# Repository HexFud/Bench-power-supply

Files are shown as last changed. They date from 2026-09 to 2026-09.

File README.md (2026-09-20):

# Bench-power-supply

I designed a simple and cost effective bench power supply for everyone.
To simplify the assmebly process i designed in kicad a small pcb where you connect external components

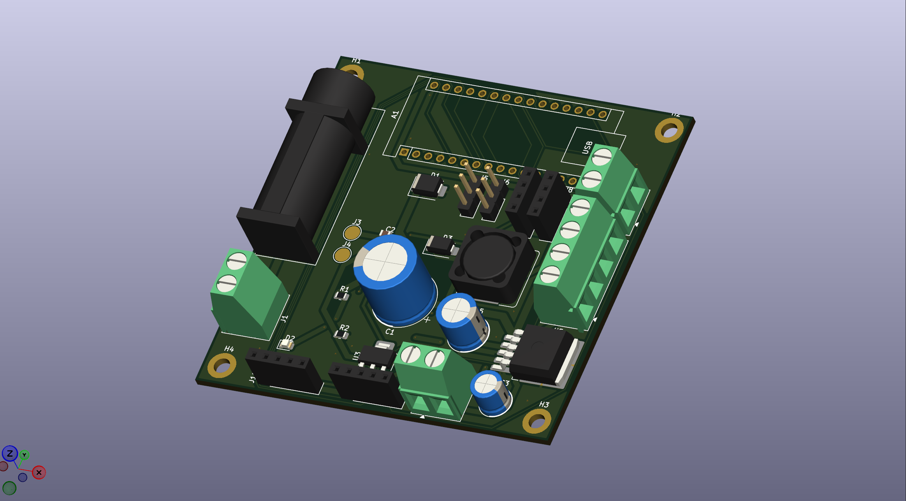
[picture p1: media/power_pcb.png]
PCB 3D model
 

## Specifications
* IN Voltage: 24V DC
* Power Module: compatible with buck modules CC/CV based on XL4015 (5A) or XL4016 (8A)

## Included Protections
* 6.3A fusible
* schottky diode to protect against invers polarity
* filtering capacitor

## First power-up

1. Do not plug the Nano, the DPS and the displays yet.
2. Power the PCB with 24V and check the 12V rail after the LM2596 and the 3V3 rail.
3. Power off, plug everything in, and power on again with no load on the output.
4. The output stays OFF at boot; enable it with a long press on the voltage encoder.

## Firmware

* Arduino IDE, board "Arduino Nano ESP32"
* Libraries: Adafruit SSD1306, Adafruit GFX Library
* Firmware: `Firmware/bench_psu.ino`
* Register addresses and scales are constants at the top of the sketch: check them against
  the protocol document of your DPS module.

## ⚠️ Crucial Assembly Notes

1. **Modifying the Buck Converter:** 
   To mount the voltage and current controls on the front panel, you must physically desolder the original tiny blue trimmers from the purchased Buck module. Solder wires into those remaining through-holes and route them to your front-panel potentiometers.
2. **Display Wiring (CRITICAL - DO NOT BURN YOUR DISPLAY):** 
   When using the standard 5-wire Chinese dual meters (3 thin wires, 2 thick wires), **THE THIN BLACK WIRE MUST BE LEFT UNCONNECTED**. The meter derives its ground reference entirely through the thick black wire. Connecting both black wires creates a ground loop that will melt the thin wire instantly under load. (Connector `J8` on this PCB is purposely designed with only 3 pins for the thin wires).
3. **High-Current Traces:** 
   The PCB tracks handling the 24V input, the Buck module, and the outputs carry up to 5–8A. When routing the PCB, ensure power traces are made very wide (min. 2mm–3mm) or left exposed so you can reinforce them with solder.

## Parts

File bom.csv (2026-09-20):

Ref | Qty | Component | Value / Notes | KiCad Footprint | Supplier | LCSC Search Link | Est. Price USD (line total)
A1 | 1 | Arduino Nano ESP32 |  | Module:Arduino_Nano | Arduino Store / Mouser | https://it.aliexpress.com/item/1005009296627043.html | 5
C1 | 1 | Electrolytic capacitor | 1000uF 50V, radial 12.5 mm | Capacitor_THT:CP_Radial_D12.5mm_P5.00mm | LCSC | https://www.lcsc.com/search?q=1000uF+50V+radial | 0,82
C2 | 1 | Ceramic capacitor | 100nF 50V X7R, 0805 | Capacitor_SMD:C_0805_2012Metric | LCSC | https://www.lcsc.com/search?q=100nF+50V+0805 | 0,94
C3 | 1 | Electrolytic capacitor | 100uF 25V, radial 6.3 mm (change symbol to C_Polarized) | Capacitor_THT:CP_Radial_D6.3mm_P2.50mm | LCSC | https://www.lcsc.com/search?q=100uF+25V+radial | 0.1
C4 | 1 | Tantalum capacitor | 22uF 16V, case B (AMS1117 stability) | Capacitor_Tantalum_SMD:CP_EIA-3528-21_Kemet-B | LCSC | https://www.lcsc.com/search?q=22uF+16V+tantalum | 0.2
C5 | 1 | Low-ESR electrolytic capacitor | 220uF 25V or higher, radial 8 mm (change symbol to C_Polarized) | Capacitor_THT:CP_Radial_D8.0mm_P3.50mm | LCSC | https://www.lcsc.com/search?q=220uF+25V+low+ESR | 0.3
D1 | 1 | SMBJ36A unidirectional TVS | Not the CA version (bidirectional) | Diode_SMD:D_SMB | LCSC | https://www.lcsc.com/search?q=SMBJ36A | 0.50
D2 | 1 | LED 0805 | Power indicator | LED_SMD:LED_0805_2012Metric | LCSC | https://www.lcsc.com/search?q=LED+0805 | 0.03
D3 | 1 | SS36 Schottky diode | 3A 60V, SMA | Diode_SMD:D_SMA | LCSC | https://www.lcsc.com/search?q=SS36 | 0.15
F1 | 1 | 6.3A 5x20 fuse + fuse holder | Pick the holder first, then adapt the footprint | Fuse:Fuseholder_Cylinder-5x20mm_Bulgin_FX0457_Horizontal_Closed | LCSC | https://www.lcsc.com/search?q=5x20+fuse+holder+PCB | 1.0
J1 | 1 | 2-pin screw terminal | 5.08 mm, 24V input | TerminalBlock_Phoenix:TerminalBlock_Phoenix_MKDS-1,5-2-5.08_1x02_P5.08mm_Horizontal | LCSC | https://www.lcsc.com/search?q=5.08mm+screw+terminal+2P | 0.5
J7 | 1 | 4-pin screw terminal | 5.08 mm, to the DPS module | TerminalBlock_Phoenix:TerminalBlock_Phoenix_MKDS-1,5-4-5.08_1x04_P5.08mm_Horizontal | LCSC | https://www.lcsc.com/search?q=5.08mm+screw+terminal+4P | 0.8
J2, J8 | 2 | 1x4 female header | I2C displays (GND, 3V3, SDA, SCL): check the pin order of your modules | Connector_PinSocket_2.54mm:PinSocket_1x04_P2.54mm_Vertical | LCSC | https://www.lcsc.com/search?q=female+header+1x4+2.54 | 0.3
J9, J10 | 2 | 1x5 female header | Encoders (GND, 3V3, SW, DT, CLK) | Connector_PinSocket_2.54mm:PinSocket_1x05_P2.54mm_Vertical | LCSC | https://www.lcsc.com/search?q=female+header+1x5+2.54 | 0.3
J5 | 1 | 1x3 female header | Serial to DPS (TX, RX, GND); delete J6 | Connector_PinSocket_2.54mm:PinSocket_1x03_P2.54mm_Vertical | LCSC | https://www.lcsc.com/search?q=female+header+1x3+2.54 | 0.2
L1 | 1 | Power inductor | 47uH, at least 3.5A (e.g. SRR1260 series); check the LM2596 datasheet nomograph | Inductor_SMD:L_Bourns_SRR1260 | LCSC | https://www.lcsc.com/search?q=SRR1260-470M | 1.50
R1, R2 | 2 | 10k resistor | 0805 | Resistor_SMD:R_0805_2012Metric | LCSC | https://www.lcsc.com/search?q=10k+0805 | 0.04
U3 | 1 | AMS1117-3.3 regulator | SOT-223 (fed from the 12V rail) | Package_TO_SOT_SMD:SOT-223-3_TabPin2 | LCSC | https://www.lcsc.com/search?q=AMS1117-3.3 | 0.2
U5 | 1 | LM2596S-12 regulator | TO-263-5 | Package_TO_SOT_SMD:TO-263-5_TabPin3 | LCSC | https://www.lcsc.com/search?q=LM2596S-12 | 1.5
- | 1 | Riden DPS5005 communication version | Programmable buck 0-50V 5A, 6-55V input, Modbus serial. With a 24V input the output tops out around 23V | - | AliExpress / Amazon / Riden resellers | https://it.aliexpress.com/item/1005003611553445.html | 30
SW1, SW2 | 2 | SPST switch 10A DC | Rated for DC current | (external, on terminals) | Amazon / AliExpress | https://it.aliexpress.com/item/1005005261096988.html | 4.0
- | 2 | 0.96 inch I2C OLED display | Check pin order (GND, VCC, SCL, SDA) | (external) | Amazon / AliExpress | https://it.aliexpress.com/item/1005006141235306.html | 6.0
- | 2 | KY-040 encoder module | Correct pin-to-pin cable to J9/J10 | (external) | Amazon / AliExpress | https://it.aliexpress.com/item/1005006060621481.html | 3.0
- | 2 | Encoder knob | May be included with encoder purchase | (external) | Amazon / AliExpress |  | 2.0
- | 1 | Banana binding post pair (red and black) | Rated for 5A | (external) | Amazon / AliExpress | https://it.aliexpress.com/item/1005005610222281.html | 4.0
- | 1 | 24V DC power supply | At least 5A | (external) | Amazon / AliExpress | https://www.amazon.it/Security-01-Alimentatore-spina-Plug-XH2400-1500WG/dp/B0CJFH8T6C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 | 13
- | 1 | Custom PCB (batch of 5-10) | Fabrication + shipping | (Gerber files) | JLCPCB or similar |  | 20
- | 1 | 2-channel oscilloscope | for ripple and noise analysis | (external) | Amazon / AliExpress | https://it.aliexpress.com/item/1005009751654965.html | 160.0
TOTAL |  |  |  |  |  |  | 254

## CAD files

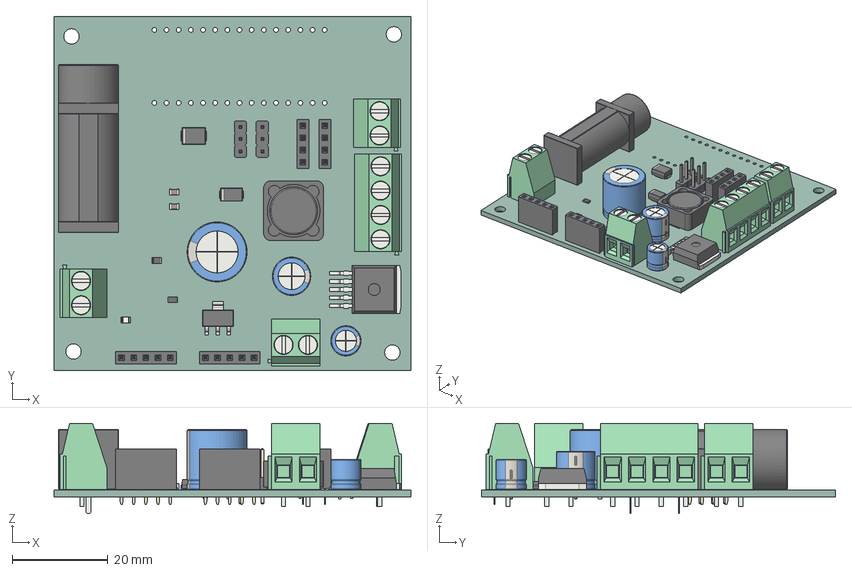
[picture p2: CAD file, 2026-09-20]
CAD/PCB_3DModel.step
74.4 x 73.9 x 18.8 mm
C_0805_2012Metric x 2
TerminalBlock_Phoenix_MKDS-1,5-2-5.08_1x02_P5.08mm_Horizontal x 3
PinSocket_1x05_P2.54mm_Vertical x 2
R_0805_2012Metric x 2
PinHeader_1x03_P254mm_Vertical x 2
SRR1260
a648ce37-9c39-11ed-93f0-dde97e994e83_part
a648ce38-9c39-11ed-93f0-dde97e994e83_part
a648ce39-9c39-11ed-93f0-dde97e994e83_part
D_SMB
CP_Radial_D63mm_P250mm
CP_Radial_D80mm_P350mm
SOT-223
PinSocket_1x04_P2.54mm_Vertical x 2
LED_0805_2012Metric
CP_Radial_D125mm_P500mm
D_SMA
TerminalBlock_Phoenix_MKDS-1,5-4-5.08_1x04_P5.08mm_Horizontal
A_Bulgin_FX0457
Bench_Power_supply_PCB

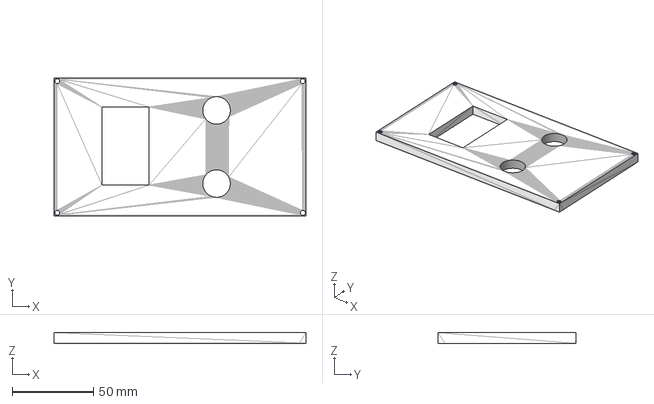
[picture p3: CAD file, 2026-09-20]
Production/PSU_CASE_FRONT.step
155.0 x 85.0 x 6.54 mm

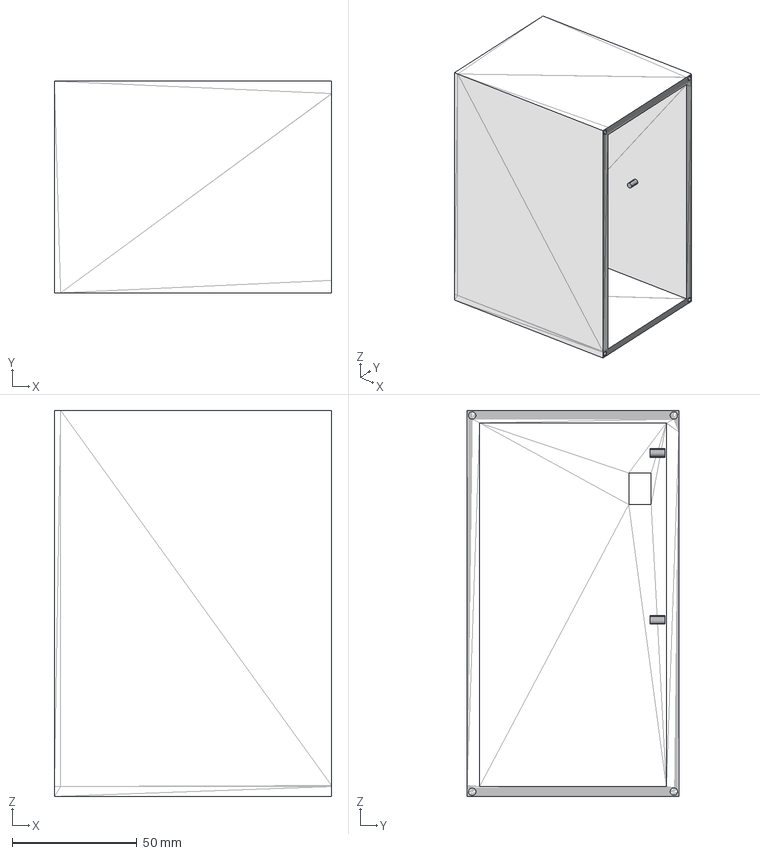
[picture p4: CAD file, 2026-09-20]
Production/PSU_CASE_BACK.step
111.3 x 85.0 x 155.0 mm

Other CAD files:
CAD/Power Supply.f3z

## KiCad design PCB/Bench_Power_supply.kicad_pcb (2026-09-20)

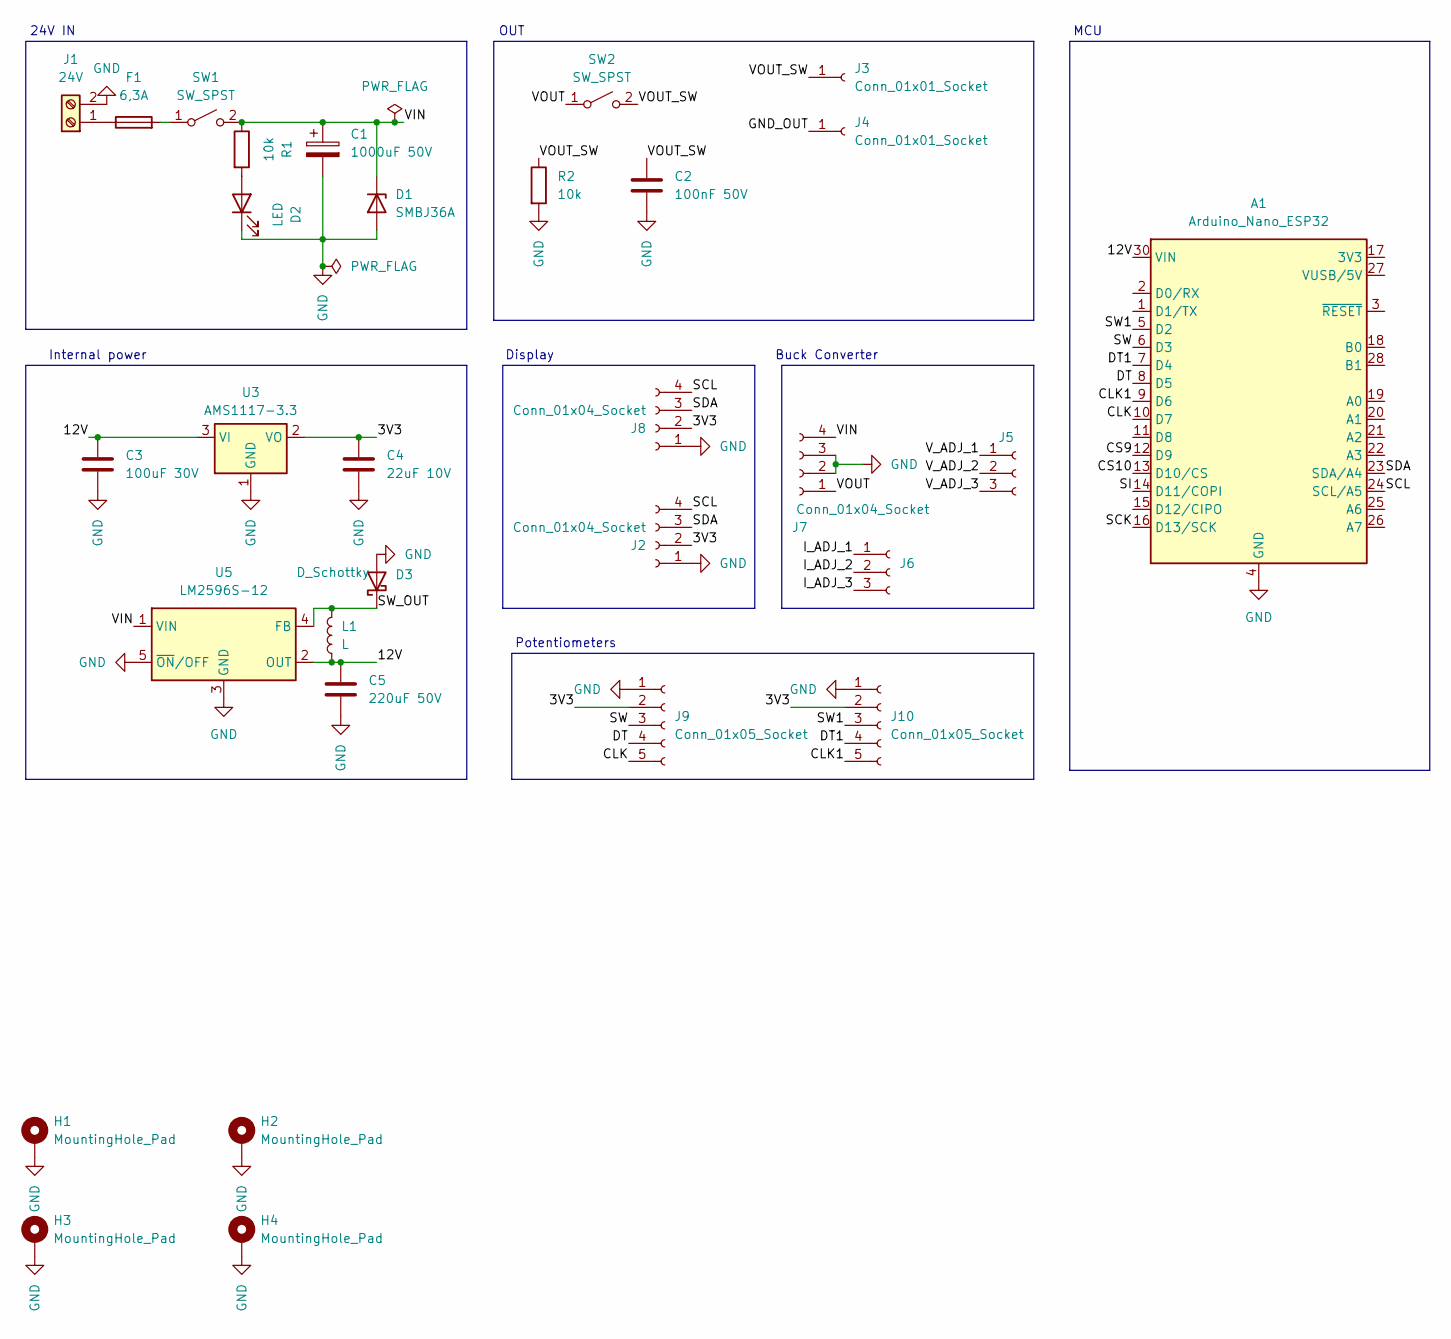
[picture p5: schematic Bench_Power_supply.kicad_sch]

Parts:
A1: Arduino_Nano_ESP32; Arduino_Nano
C1: 1000uF 50V; CP_Radial_D12.5mm_P5.00mm
C2: 100nF 50V; C_0805_2012Metric
C3: 100uF 30V; CP_Radial_D6.3mm_P2.50mm
C4: 22uF 10V; C_0805_2012Metric
C5: 220uF 50V; CP_Radial_D8.0mm_P3.50mm
D1: SMBJ36A; D_SMB
D2: LED; LED_0805_2012Metric
D3: D_Schottky; D_SMA
F1: 6,3A; Fuseholder_Cylinder-5x20mm_Bulgin_FX0457_Horizontal_Closed
H1, H2, H3, H4: MountingHole_Pad; MountingHole_3.2mm_M3_DIN965_Pad
J1: 24V; TerminalBlock_Phoenix_MKDS-1,5-2-5.08_1x02_P5.08mm_Horizont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
J2, J8: Conn_01x04_Socket; PinSocket_1x04_P2.54mm_Vertical
J3, J4: Conn_01x01_Socket; TestPoint_Pad_D3.0mm
J5, J6: Conn_01x03_Socket; PinHeader_1x03_P2.54mm_Vertical
J7: Conn_01x04_Socket; TerminalBlock_Phoenix_MKDS-1,5-4-5.08_1x04_P5.08mm_Horizont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
J9, J10: Conn_01x05_Socket; PinSocket_1x05_P2.54mm_Vertical
L1: L; L_Bourns_SRR1260
R1, R2: 10k; R_0805_2012Metric
SW1, SW2: SW_SPST; TerminalBlock_Phoenix_MKDS-1,5-2-5.08_1x02_P5.08mm_Horizont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
U3: AMS1117-3.3; SOT-223-3_TabPin2
U5: LM2596S-12; TO-263-5_TabPin3

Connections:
/3V3: C4.1, J2.2, J8.2, J9.2, J10.2, U3.2 (VO)
/12V: A1.30 (VIN), C3.1, C5.1, L1.1, U3.3 (VI), U5.2 (OUT)
/CLK: A1.10 (D7), J9.5
/CLK1: A1.9 (D6), J10.5
/CS9: A1.12 (D9)
/CS10: A1.13 (D10/CS)
/DT: A1.8 (D5), J9.4
/DT1: A1.7 (D4), J10.4
/GND_OUT: J4.1 (Pin_1_1)
/I_ADJ_1: J6.1
/I_ADJ_2: J6.2
/I_ADJ_3: J6.3
/SCK: A1.16 (D13/SCK)
/SCL: A1.24 (SCL/A5), J2.4, J8.4
/SDA: A1.23 (SDA/A4), J2.3, J8.3
/SI: A1.14 (D11/COPI)
/SW: A1.6 (D3), J9.3
/SW1: A1.5 (D2), J10.3
/SW_OUT: D3.1 (K), L1.2, U5.4 (FB)
/VIN: C1.1, D1.1 (K), J7.4, R1.1, SW1.2 (B), U5.1 (VIN)
/VOUT: J7.1, SW2.1 (A)
/VOUT_SW: C2.1, J3.1 (Pin_1_1), R2.1, SW2.2 (B)
/V_ADJ_1: J5.1
/V_ADJ_2: J5.2
/V_ADJ_3: J5.3
GND: A1.4 (GND), A1.29 (GND), C1.2, C2.2, C3.2, C4.2, C5.2, D1.2 (A), D2.1 (K), D3.2 (A), H1.1 (1_1), H2.1 (1_1), H3.1 (1_1), H4.1 (1_1), J1.2, J2.1, J7.2, J7.3, J8.1, J9.1, J10.1, R2.2, U3.1 (GND), U5.3 (GND), U5.5 (~ON/OFF)
unnamed: D2.2 (A), R1.2
unnamed: F1.1, J1.1
unnamed: F1.2, SW1.1 (A)

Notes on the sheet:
Internal power
Buck Converter
Display
Potentiometers
MCU
OUT
24V IN

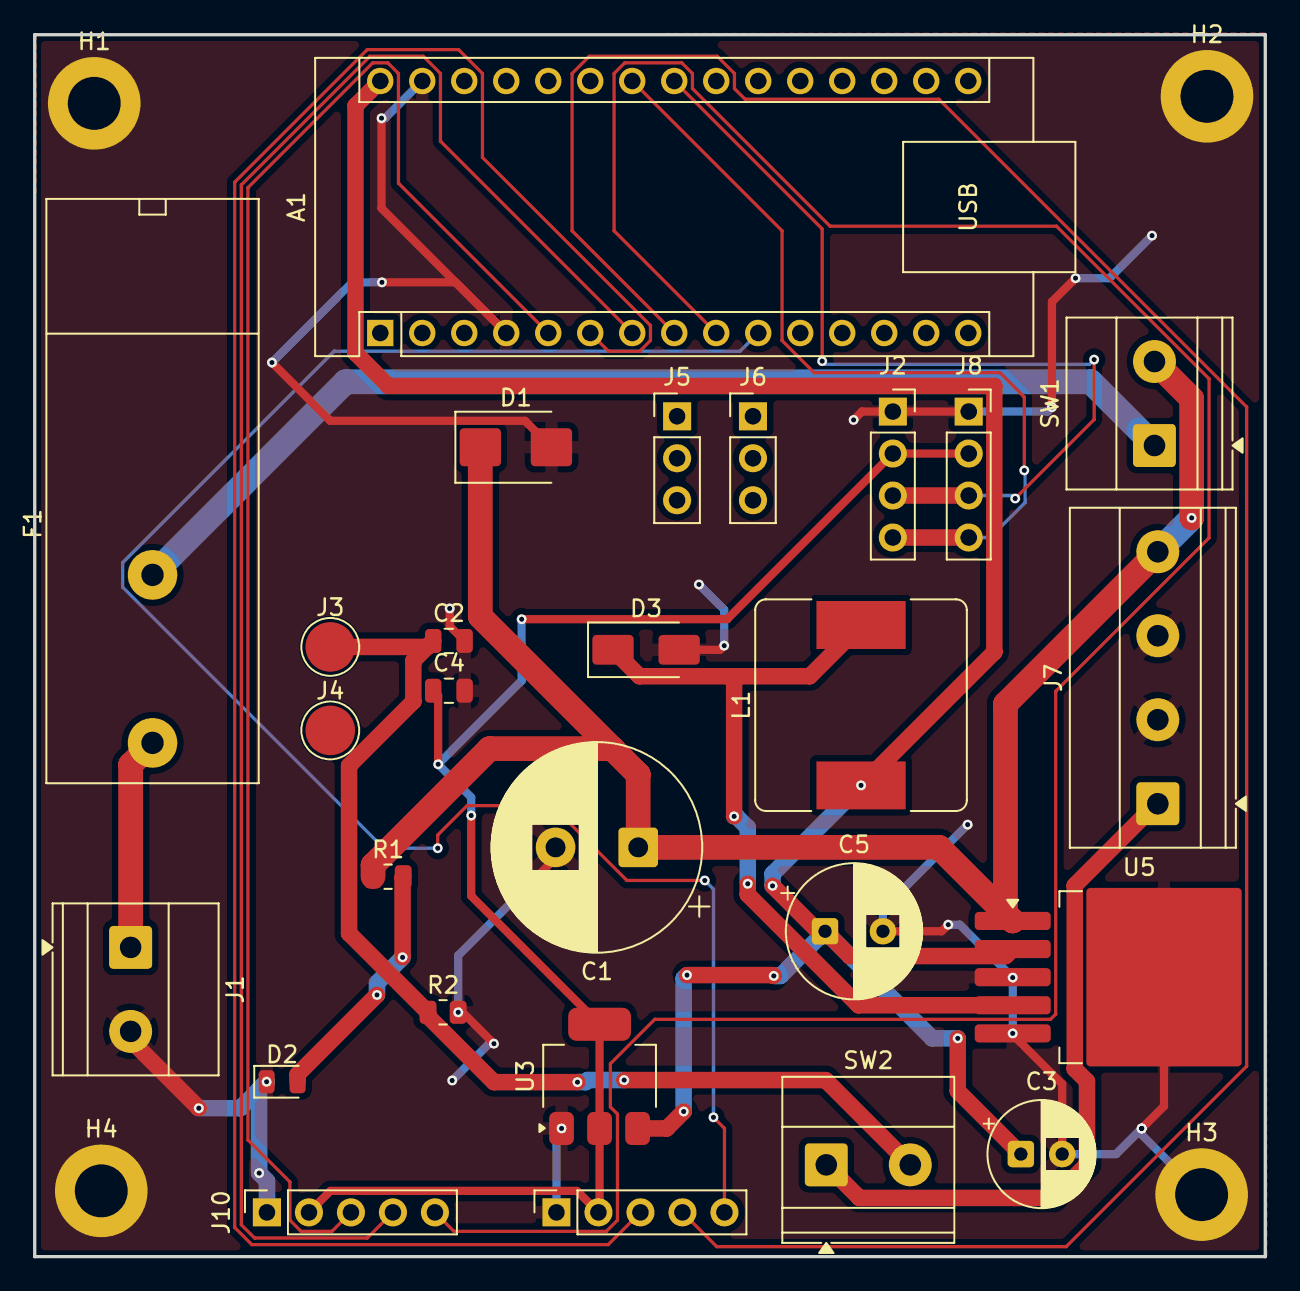
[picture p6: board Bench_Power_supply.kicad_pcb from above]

Board: 2 copper layers, 74.4 x 73.9 mm, 31 parts (0 on the bottom side), 18 nets.

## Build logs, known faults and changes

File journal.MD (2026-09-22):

## 19 September 1,14 Hours
This is the day 1 of building my own bench power supply. I started designing the schematic, and then routed the components on the PCB. Very easy job

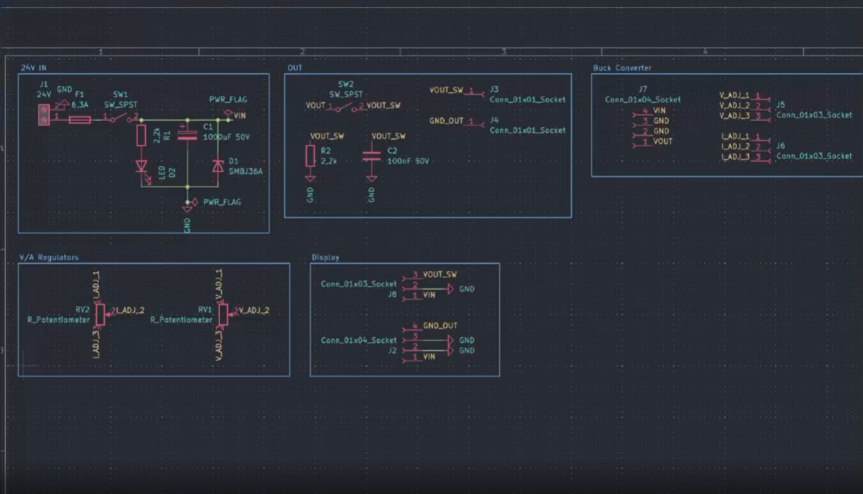
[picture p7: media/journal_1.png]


## 20 Septmeber 1,93 Hours
I have done a lot of progressed in only one day. I started the day by designing the case for the PCB 

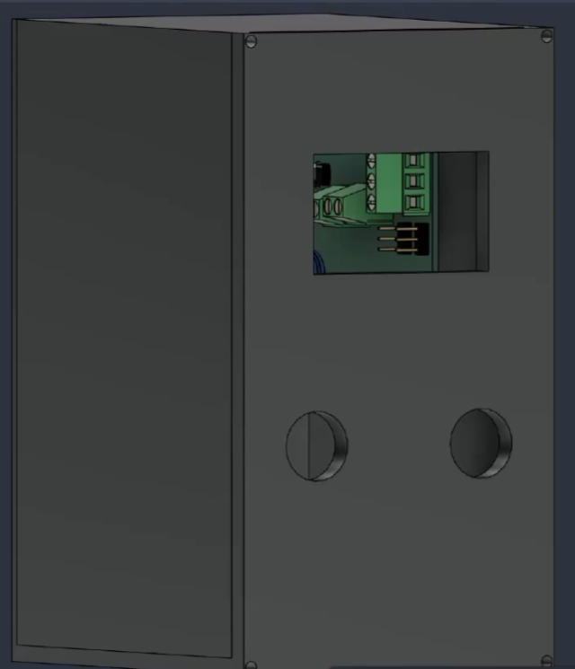
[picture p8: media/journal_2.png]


After procrastinating for a bit i thoutght about the PCB and i said to myself, this is to simple so I'm back editing the PCB! I added a lot of components to make the PSU "smart".

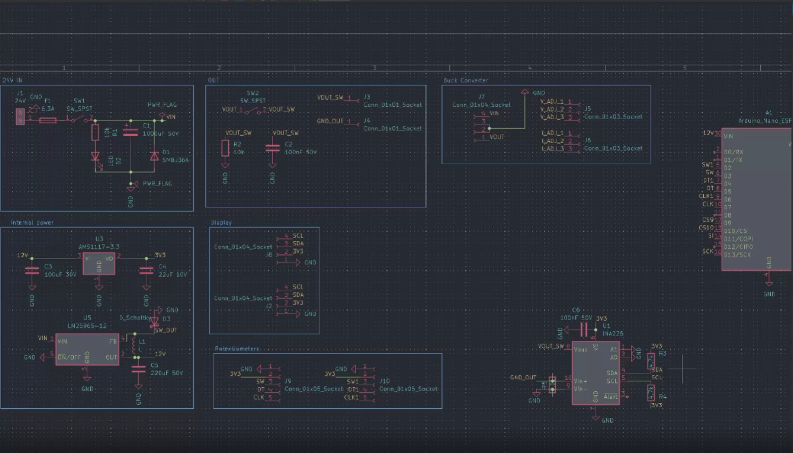
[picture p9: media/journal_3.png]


## 21 September 

I have polished the PCB and the 3D model a bit. I think this project is now complete but maybe i will update this again!

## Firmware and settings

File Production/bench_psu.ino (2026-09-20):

#include <Arduino.h>
#include <Wire.h>
#include <Adafruit_GFX.h>
#include <Adafruit_SSD1306.h>

static const uint8_t ENC_V_CLK = 10, ENC_V_DT = 8, ENC_V_SW = 6;
static const uint8_t ENC_I_CLK = 9, ENC_I_DT = 7, ENC_I_SW = 5;
static const uint8_t DPS_RX_PIN = 44;
static const uint8_t DPS_TX_PIN = 43;
static const uint8_t I2C_SDA_PIN = 11;
static const uint8_t I2C_SCL_PIN = 12;

static const bool ENC_V_INVERT = false;
static const bool ENC_I_INVERT = false;

static const uint8_t  DPS_ADDR = 1;
static const uint32_t DPS_BAUD = 9600;

static const uint16_t REG_USET   = 0x0000;
static const uint16_t REG_ISET   = 0x0001;
static const uint16_t REG_UOUT   = 0x0002;
static const uint16_t REG_IOUT   = 0x0003;
static const uint16_t REG_UIN    = 0x0005;
static const uint16_t REG_PROT   = 0x0007;
static const uint16_t REG_CVCC   = 0x0008;
static const uint16_t REG_ONOFF  = 0x0009;
static const uint16_t REG_COUNT  = 10;
static const float    V_SCALE = 100.0f;
static const float    I_SCALE = 1000.0f;

static const float V_MAX_CFG    = 23.0f;
static const float I_MAX_CFG    = 5.0f;
static const float VIN_HEADROOM = 1.5f;

static const float V_STEPS[] = {0.01f, 0.1f, 1.0f};
static const float I_STEPS[] = {0.001f, 0.01f, 0.1f};

#define USE_DISPLAY2 1
static const uint8_t OLED1_ADDR = 0x3C;
static const uint8_t OLED2_ADDR = 0x3D;

static const uint32_t POLL_MS       = 250;
static const uint32_t DRAW_MS       = 100;
static const uint32_t WRITE_GAP_MS  = 40;
static const uint32_t SYNC_HOLD_MS  = 600;
static const uint32_t LONG_PRESS_MS = 800;

#define dpsSerial Serial1
static Adafruit_SSD1306 oled1(128, 64, &Wire, -1);
#if USE_DISPLAY2
static Adafruit_SSD1306 oled2(128, 64, &Wire, -1);
#endif
static bool oled1Ok = false, oled2Ok = false;

struct DpsState {
  float uset = 0, iset = 0, uout = 0, iout = 0, uin = 0;
  bool cc = false, on = false, linkOk = false;
  uint8_t prot = 0;
};
static DpsState dps;

struct Encoder {
  uint8_t pinA, pinB;
  bool invert;
  volatile uint8_t state;
  volatile int32_t acc;
};

enum BtnEvent { BTN_NONE, BTN_SHORT, BTN_LONG };

struct Button {
  uint8_t pin;
  bool down;
  bool longFired;
  uint32_t tChange, tPress;
};

static float targetV = 0.0f, targetI = 0.5f;
static bool dirtyV = false, dirtyI = false;
static uint32_t lastEditMs = 0, lastWriteMs = 0, lastPollMs = 0, lastDrawMs = 0;
static uint8_t stepIdxV = 1, stepIdxI = 1;

static uint16_t crc16(const uint8_t* d, size_t n) {
  uint16_t crc = 0xFFFF;
  for (size_t i = 0; i < n; i++) {
    crc ^= d[i];
    for (int b = 0; b < 8; b++) crc = (crc & 1) ? (crc >> 1) ^ 0xA001 : (crc >> 1);
  }
  return crc;
}

static bool txrx(const uint8_t* req, size_t reqLen, uint8_t* resp, size_t respLen) {
  while (dpsSerial.available()) dpsSerial.read();
  dpsSerial.write(req, reqLen);
  dpsSerial.flush();
  size_t n = 0;
  uint32_t t0 = millis();
  while (n < respLen && millis() - t0 < 100) {
    if (dpsSerial.available()) resp[n++] = (uint8_t)dpsSerial.read();
    else delay(1);
  }
  return n == respLen;
}

static bool readRegs(uint16_t start, uint16_t count, uint16_t* out) {
  if (count == 0 || count > 16) return false;
  uint8_t req[8] = {DPS_ADDR, 0x03, (uint8_t)(start >> 8), (uint8_t)(start & 0xFF),
                    (uint8_t)(count >> 8), (uint8_t)(count & 0xFF), 0, 0};
  uint16_t c = crc16(req, 6);
  req[6] = c & 0xFF;
  req[7] = c >> 8;

  uint8_t resp[5 + 2 * 16];
  size_t rl = 5 + 2 * (size_t)count;
  if (!txrx(req, 8, resp, rl)) return false;
  if (resp[0] != DPS_ADDR || resp[1] != 0x03 || resp[2] != 2 * count) return false;
  uint16_t rc = crc16(resp, rl - 2);
  if (resp[rl - 2] != (rc & 0xFF) || resp[rl - 1] != (rc >> 8)) return false;
  for (uint16_t i = 0; i < count; i++) out[i] = ((uint16_t)resp[3 + 2 * i] << 8) | resp[4 + 2 * i];
  return true;
}

static bool writeReg(uint16_t reg, uint16_t val) {
  uint8_t req[8] = {DPS_ADDR, 0x06, (uint8_t)(reg >> 8), (uint8_t)(reg & 0xFF),
                    (uint8_t)(val >> 8), (uint8_t)(val & 0xFF), 0, 0};
  uint16_t c = crc16(req, 6);
  req[6] = c & 0xFF;
  req[7] = c >> 8;
  uint8_t resp[8];
  if (!txrx(req, 8, resp, 8)) return false;
  return memcmp(req, resp, 8) == 0;
}

static bool pollDps() {
  uint16_t r[REG_COUNT];
  if (!readRegs(REG_USET, REG_COUNT, r)) {
    dps.linkOk = false;
    return false;
  }
  dps.uset = r[REG_USET] / V_SCALE;
  dps.iset = r[REG_ISET] / I_SCALE;
  dps.uout = r[REG_UOUT] / V_SCALE;
  dps.iout = r[REG_IOUT] / I_SCALE;
  dps.uin  = r[REG_UIN]  / V_SCALE;
  dps.prot = (uint8_t)r[REG_PROT];
  dps.cc   = (r[REG_CVCC] == 1);
  dps.on   = (r[REG_ONOFF] == 1);
  dps.linkOk = true;
  return true;
}

DRAM_ATTR static const int8_t ENC_TABLE[16] = {0, -1, 1, 0, 1, 0, 0, -1, -1, 0, 0, 1, 0, 1, -1, 0};

static Encoder encV = {ENC_V_CLK, ENC_V_DT, ENC_V_INVERT, 0, 0};
static Encoder encI = {ENC_I_CLK, ENC_I_DT, ENC_I_INVERT, 0, 0};
static portMUX_TYPE encMux = portMUX_INITIALIZER_UNLOCKED;

static void IRAM_ATTR encIsr(void* arg) {
  Encoder* e = (Encoder*)arg;
  uint8_t s = (uint8_t)((digitalRead(e->pinA) << 1) | digitalRead(e->pinB));
  e->state = ((e->state << 2) | s) & 0x0F;
  e->acc = e->acc + ENC_TABLE[e->state];
}

static int32_t takeDetents(Encoder& e) {
  portENTER_CRITICAL(&encMux);
  int32_t a = e.acc;
  int32_t d = a / 4;
  e.acc = a - d * 4;
  portEXIT_CRITICAL(&encMux);
  return e.invert ? -d : d;
}

static void encBegin(Encoder& e) {
  pinMode(e.pinA, INPUT_PULLUP);
  pinMode(e.pinB, INPUT_PULLUP);
  e.state = (uint8_t)((digitalRead(e.pinA) << 1) | digitalRead(e.pinB));
  attachInterruptArg(digitalPinToInterrupt(e.pinA), encIsr, &e, CHANGE);
  attachInterruptArg(digitalPinToInterrupt(e.pinB), encIsr, &e, CHANGE);
}

static Button btnV = {ENC_V_SW, false, false, 0, 0};
static Button btnI = {ENC_I_SW, false, false, 0, 0};

static BtnEvent pollButton(Button& b) {
  uint32_t now = millis();
  bool pressed = (digitalRead(b.pin) == LOW);
  if (pressed != b.down && now - b.tChange > 25) {
    b.tChange = now;
    b.down = pressed;
    if (pressed) {
      b.tPress = now;
      b.longFired = false;
    } else if (!b.longFired) {
      return BTN_SHORT;
    }
  }
  if (b.down && !b.longFired && now - b.tPress > LONG_PRESS_MS) {
    b.longFired = true;
    return BTN_LONG;
  }
  return BTN_NONE;
}

static float effectiveVmax() {
  float vmax = V_MAX_CFG;
  if (dps.linkOk && dps.uin > 1.0f) {
    float lim = dps.uin - VIN_HEADROOM;
    if (lim < vmax) vmax = lim;
  }
  return vmax < 0 ? 0 : vmax;
}

static float clampf(float v, float lo, float hi) {
  return v < lo ? lo : (v > hi ? hi : v);
}

static void setOutput(bool on) {
  if (writeReg(REG_ONOFF, on ? 1 : 0)) dps.on = on;
}

static void handleInputs() {
  int32_t dv = takeDetents(encV);
  if (dv != 0) {
    targetV = clampf(targetV + dv * V_STEPS[stepIdxV], 0.0f, effectiveVmax());
    dirtyV = true;
    lastEditMs = millis();
  }
  int32_t di = takeDetents(encI);
  if (di != 0) {
    targetI = clampf(targetI + di * I_STEPS[stepIdxI], 0.0f, I_MAX_CFG);
    dirtyI = true;
    lastEditMs = millis();
  }

  BtnEvent ev = pollButton(btnV);
  if (ev == BTN_SHORT) stepIdxV = (stepIdxV + 1) % (sizeof(V_STEPS) / sizeof(V_STEPS[0]));
  if (ev == BTN_LONG) setOutput(!dps.on);

  ev = pollButton(btnI);
  if (ev == BTN_SHORT) stepIdxI = (stepIdxI + 1) % (sizeof(I_STEPS) / sizeof(I_STEPS[0]));
  if (ev == BTN_LONG) setOutput(false);
}

static void sendPending() {
  if (millis() - lastWriteMs < WRITE_GAP_MS) return;
  if (dirtyV) {
    if (writeReg(REG_USET, (uint16_t)lroundf(targetV * V_SCALE))) dirtyV = false;
    lastWriteMs = millis();
    return;
  }
  if (dirtyI) {
    if (writeReg(REG_ISET, (uint16_t)lroundf(targetI * I_SCALE))) dirtyI = false;
    lastWriteMs = millis();
  }
}

static void syncFromDps() {

  if (!dps.linkOk || dirtyV || dirtyI) return;
  if (millis() - lastEditMs < SYNC_HOLD_MS) return;
  targetV = dps.uset;
  targetI = dps.iset;
}

static void drawSetpoint() {
  if (!oled1Ok) return;
  char buf[28];
  oled1.clearDisplay();
  oled1.setTextColor(SSD1306_WHITE);
  oled1.setTextSize(1);
  oled1.setCursor(0, 0);
  oled1.print("SETPOINT");
  oled1.setCursor(78, 0);
  oled1.print(dps.on ? "OUT ON" : "OUT OFF");
  oled1.setTextSize(2);
  snprintf(buf, sizeof(buf), "%6.2f V", targetV);
  oled1.setCursor(0, 14);
  oled1.print(buf);
  snprintf(buf, sizeof(buf), "%6.3f A", targetI);
  oled1.setCursor(0, 34);
  oled1.print(buf);
  oled1.setTextSize(1);
  snprintf(buf, sizeof(buf), "step V %.2f  I %.3f", V_STEPS[stepIdxV], I_STEPS[stepIdxI]);
  oled1.setCursor(0, 56);
  oled1.print(buf);
  oled1.display();
}

#if USE_DISPLAY2
static void drawMeasured() {
  if (!oled2Ok) return;
  char buf[28];
  oled2.clearDisplay();
  oled2.setTextColor(SSD1306_WHITE);
  oled2.setTextSize(1);
  oled2.setCursor(0, 0);
  oled2.print("MEASURED");
  oled2.setCursor(78, 0);
  oled2.print(!dps.linkOk ? "NO LINK" : (dps.cc ? "CC" : "CV"));
  oled2.setTextSize(2);
  snprintf(buf, sizeof(buf), "%6.2f V", dps.uout);
  oled2.setCursor(0, 14);
  oled2.print(buf);
  snprintf(buf, sizeof(buf), "%6.3f A", dps.iout);
  oled2.setCursor(0, 34);
  oled2.print(buf);
  oled2.setTextSize(1);
  oled2.setCursor(0, 56);
  if (dps.linkOk && dps.prot != 0) {
    const char* names[] = {"", "OVP", "OCP", "OPP"};
    snprintf(buf, sizeof(buf), "PROTEZIONE: %s", dps.prot <= 3 ? names[dps.prot] : "?");
  } else {
    snprintf(buf, sizeof(buf), "P %.1fW  Vin %.1fV", dps.uout * dps.iout, dps.uin);
  }
  oled2.print(buf);
  oled2.display();
}
#endif

void setup() {
  Serial.begin(115200);

  pinMode(ENC_V_SW, INPUT_PULLUP);
  pinMode(ENC_I_SW, INPUT_PULLUP);
  encBegin(encV);
  encBegin(encI);

  dpsSerial.begin(DPS_BAUD, SERIAL_8N1, DPS_RX_PIN, DPS_TX_PIN);

  Wire.begin(I2C_SDA_PIN, I2C_SCL_PIN);
  Wire.setClock(400000);
  oled1Ok = oled1.begin(SSD1306_SWITCHCAPVCC, OLED1_ADDR);
#if USE_DISPLAY2
  oled2Ok = oled2.begin(SSD1306_SWITCHCAPVCC, OLED2_ADDR);
#endif
  Serial.printf("OLED1=%d OLED2=%d\n", oled1Ok, oled2Ok);

  if (pollDps()) {
    targetV = dps.uset;
    targetI = dps.iset;
  }
  Serial.printf("DPS link: %s\n", dps.linkOk ? "OK" : "NO");
}

void loop() {
  uint32_t now = millis();

  handleInputs();
  sendPending();

  if (now - lastPollMs >= POLL_MS) {
    lastPollMs = now;
    pollDps();
    syncFromDps();
  }

  if (now - lastDrawMs >= DRAW_MS) {
    lastDrawMs = now;
    drawSetpoint();
#if USE_DISPLAY2
    drawMeasured();
#endif
  }
}

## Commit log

2026-09-20 Create BOM with estimated costs for project components
    Added a Bill of Materials (BOM) with estimated costs for components and diagnostic equipment.
    [bom.csv]
2026-09-20 Revise BOM section titles and descriptions
    Updated section titles and descriptions for clarity in the BOM.
    [bom.csv]
2026-09-20 Revise BOM with new components and pricing
    Updated the Bill of Materials (BOM) with estimated costs and additional components.
    [bom.csv]
